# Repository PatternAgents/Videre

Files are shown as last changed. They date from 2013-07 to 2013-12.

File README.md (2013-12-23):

Videre
=============

PatternAgents Videre - LCD Shield with Cortex-M0

[PatternAgents Videre  
*PatternAgents Videre*](http://www.patternagents.com/projects/Videre.html)

The PatternAgents Videre uses an ARM Cortex-M0 based Programmable System-on-Chip (PSoC4) 
to control a 16x2 Character LCD with color backlighting. The PSoC4  can read read inputs from sensors, 
switches, potentiometers, or other analog inputs and display those sensors directly on the LCD in
standalone mode. Or you can use it as an Arduino Shield, with either I2C,, UART, or SPI interface.

Features:

        16 Character x 2 Line Display

        Color LED Backlighting
	
        Selectable 3.3Volt or 5.0Volt Operation
	
        UART, I2C, SPI Interface Selectable
	
        Use as Arduino Shield or as a Standalone Display
	
        CapSense Slider Bar (optional)      

	Arduino Uno/Leonardo/Mega/Due Compatible Shield

You can read more about the PSoC4 Integrated Circuit used here : http://www.cypress.com/?mpn=CY8C4245AXI-483

[  
*Licensing CC BY-NC-SA 4.0*](http://creativecommons.org/licenses/by-nc-sa/4.0/)

PatternAgents uses the increasingly popular business model called "Dual Licensing" 
in which both the open source software distribution mechanism and traditional commercial software distribution models are combined.

Open Source Projects:        

If you are developing and distributing open source applications under the Creative Commons CC BY-NC-SA 4.0, 
as published by the Creative Commons Foundation, then you are free to use the PatternAgents hardware/software under the CC BY-NC-SA 4.0 license. 
Please note that CC BY-NC-SA 4.0 requires that all modifications to the original code as well as all Derivative Works 
must also be released under the terms of the CC BY-NC-SA 4.0 license.

Closed Source Projects:

If you are developing and distributing traditional closed source or commercial applications, 
you must purchase a PatternAgents commercial use license, 
which is specifically designed for users interested in retaining the proprietary status of their designs and code. 
All PatternAgents commercial licenses expressly supersede the CC BY-NC-SA 4.0 license. 
This means that when you license the PatternAgents software under a commercial license, 
you specifically do not use the software under the CC BY-NC-SA 4.0 license and therefore you are not subject to any of its terms.
        
If you would like to use our designs for your own personal or educational use, have at it! 

Our public design repository is available at <a href="https://github.com/patternagents">Github</a>.

If you would like to produce our designs for commercial use, or as products for sale, 
please contact us to arrange for a Commercial Use license. We have many other designs, 
as well as options and extras that are not released publicly. 
We will also customize designs, firmware, and software for a reasonable fee, just contact us to discuss your requirements.

THIS SOFTWARE IS PROVIDED BY THE CONTRIBUTORS "AS IS" AND WITHOUT ANY EXPRESS OR IMPLIED WARRANTIES, 
INCLUDING, BUT NOT LIMITED TO, THE IMPLIED WARRANTIES OF MERCHANTABILITY AND FITNESS FOR A PARTICULAR PURPOSE ARE DISCLAIMED. 
IN NO EVENT SHALL THE COPYRIGHT OWNER OR CONTRIBUTORS BE LIABLE FOR ANY DIRECT, INDIRECT, INCIDENTAL, SPECIAL, EXEMPLARY, 
OR CONSEQUENTIAL DAMAGES (INCLUDING, BUT NOT LIMITED TO, PROCUREMENT OF SUBSTITUTE GOODS OR SERVICES; LOSS OF USE, DATA, 
OR PROFITS; OR BUSINESS INTERRUPTION) HOWEVER CAUSED AND ON ANY THEORY OF LIABILITY, WHETHER IN CONTRACT, 
STRICT LIABILITY, OR TORT (INCLUDING NEGLIGENCE OR OTHERWISE) ARISING IN ANY WAY OUT OF THE USE OF THIS SOFTWARE, 
EVEN IF ADVISED OF THE POSSIBILITY OF SUCH DAMAGE. 

-------------------------------------------------------------------------------------------

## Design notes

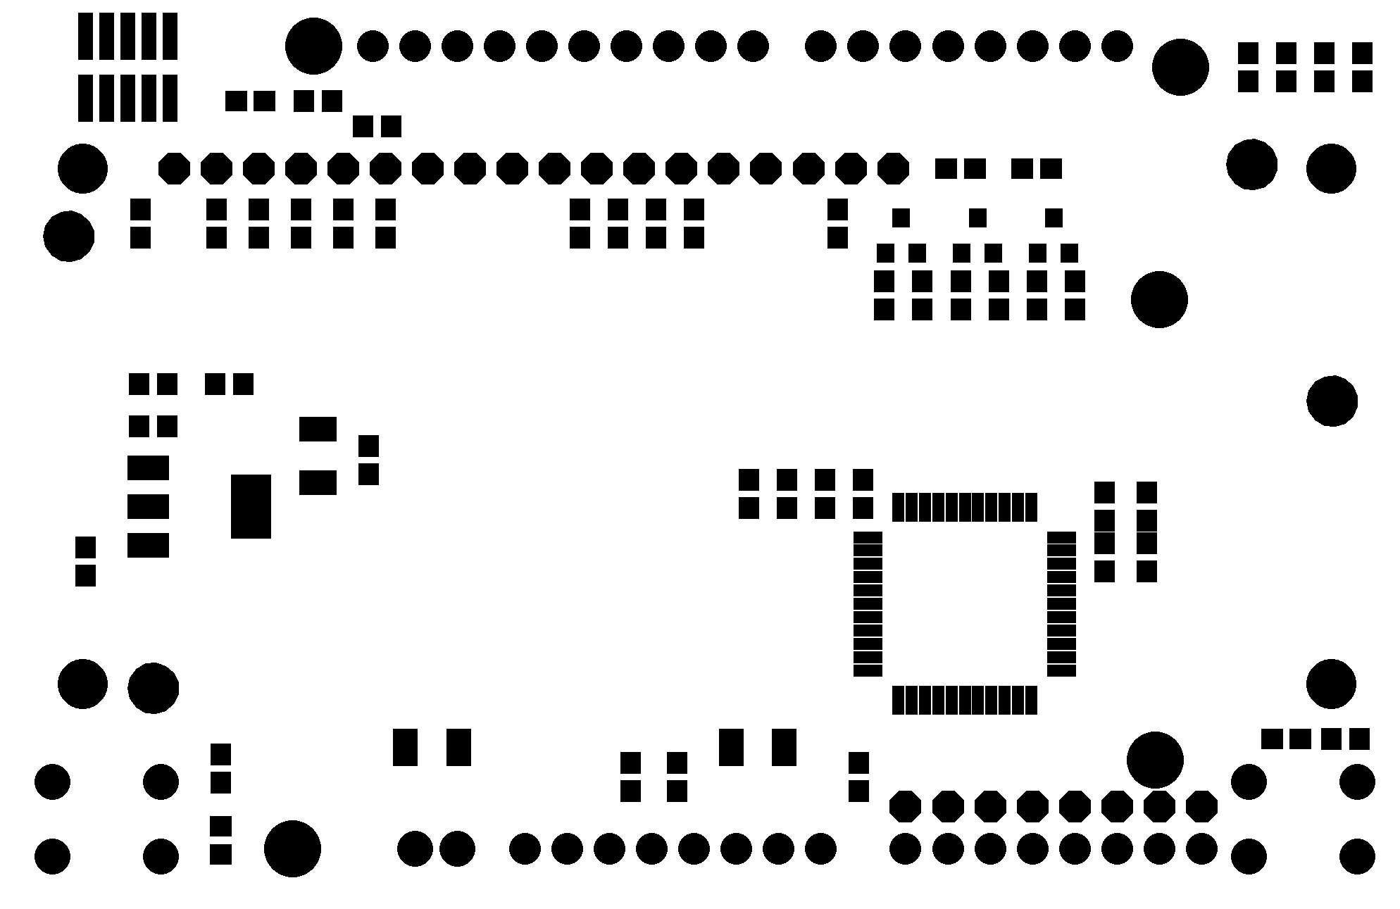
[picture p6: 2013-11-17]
Videre/eagleUp/eagleUp_Videre_top_mask.png

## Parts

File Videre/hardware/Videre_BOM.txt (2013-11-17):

Partlist  at 6/29/2013 11:25:48 AM eagle/PatternAgents/Arduino/Videre/Videre/Videre.sch

Part   Value                 Device                Package               Description                                                     
C1     0.1uF                 CAP0603-CAP           0603-CAP              Capacitor                                                       
C2     0.1uF                 CAP0603-CAP           0603-CAP              Capacitor                                                       
C3     1uF                   CAP0603-CAP           0603-CAP              Capacitor                                                       
C4     0.1uF                 CAP0603-CAP           0603-CAP              Capacitor                                                       
C5     1uF                   CAP0603-CAP           0603-CAP              Capacitor                                                       
C6     0.1uF                 CAP0603-CAP           0603-CAP              Capacitor                                                       
C7     1uF                   CAP0603-CAP           0603-CAP              Capacitor                                                       
C8     10uF                  CAP1210               1210                  Capacitor                                                       
C9     10uF                  CAP1210               1210                  Capacitor                                                       
C10    10uF                  CAP1210               1210                  Capacitor                                                       
C11    0.1uF                 CAP0603-CAP           0603-CAP              Capacitor                                                       
C12    10nF                  CAP0603-CAP           0603-CAP              Capacitor                                                       
C13    0.1uF                 CAP0603-CAP           0603-CAP              Capacitor                                                       
C14    2.2nF                 CAP0603-CAP           0603-CAP              Capacitor                                                       
J1                           M02PTH                1X02                  Header 2                                                        
JTAG1                        JTAG-CORTEXM3         2X05_1.27MM_SMT       JTAG Programming Connector                                      
Q1     MOSFET-PCHANNELSMD    MOSFET-PCHANNELSMD    SOT23-3               Generic PMOSFET                                                 
Q2     MOSFET-PCHANNELSMD    MOSFET-PCHANNELSMD    SOT23-3               Generic PMOSFET                                                 
Q3     MOSFET-PCHANNELSMD    MOSFET-PCHANNELSMD    SOT23-3               Generic PMOSFET                                                 
R1     100                   RESISTOR_SFE0603-RES  0603-RES              Resistor                                                        
R2     10K                   RESISTOR_SFE0603-RES  0603-RES              Resistor                                                        
R3     10K                   RESISTOR_SFE0603-RES  0603-RES              Resistor                                                        
R4     10K                   RESISTOR_SFE0603-RES  0603-RES              Resistor                                                        
R5     10K                   RESISTOR_SFE0603-RES  0603-RES              Resistor                                                        
R6     10K                   RESISTOR_SFE0603-RES  0603-RES              Resistor                                                        
R7     10K                   RESISTOR_SFE0603-RES  0603-RES              Resistor                                                        
R8     10K                   RESISTOR_SFE0603-RES  0603-RES              Resistor                                                        
R9     10K                   RESISTOR_SFE0603-RES  0603-RES              Resistor                                                        
R10    0                     RESISTOR_SFE0603-RES  0603-RES              Resistor                                                        
R11    10K                   RESISTOR_SFE0603-RES  0603-RES              Resistor                                                        
R12    0                     RESISTOR_SFE0603-RES  0603-RES              Resistor                                                        
R13    10K                   RESISTOR_SFE0603-RES  0603-RES              Resistor                                                        
R14    0                     RESISTOR_SFE0603-RES  0603-RES              Resistor                                                        
R15    10K                   RESISTOR_SFE0603-RES  0603-RES              Resistor                                                        
R16    4.7K                  RESISTORR0603         R0603                 RESISTOR, American symbol                                       
R17    4.7K                  RESISTORR0603         R0603                 RESISTOR, American symbol                                       
R20    4.7K                  RESISTOR_SFE0603-RES  0603-RES              Resistor                                                        
R21    10K                   RESISTOR_SFE0603-RES  0603-RES              Resistor                                                        
R22    10K                   RESISTOR_SFE0603-RES  0603-RES              Resistor                                                        
R23    0                     RESISTOR_SFE0603-RES  0603-RES              Resistor                                                        
R24    0                     RESISTOR_SFE0603-RES  0603-RES              Resistor                                                        
R25    0                     RESISTOR_SFE0603-RES  0603-RES              Resistor                                                        
R26    0                     RESISTOR_SFE0603-RES  0603-RES              Resistor                                                        
R27    0                     RESISTOR_SFE0603-RES  0603-RES              Resistor                                                        
R28    0                     RESISTOR_SFE0603-RES  0603-RES              Resistor                                                        
R29    240                   RESISTORR0603         R0603                 RESISTOR, American symbol                                       
R30    390                   RESISTORR0603         R0603                 RESISTOR, American symbol                                       
R31    330                   RESISTORR0603         R0603                 RESISTOR, American symbol                                       
R32    0                     RESISTOR_SFE0603-RES  0603-RES              Resistor                                                        
R33    330                   RESISTORR0603         R0603                 RESISTOR, American symbol                                       
R34    330                   RESISTORR0603         R0603                 RESISTOR, American symbol                                       
R35    180                   RESISTOR_SFE0603-RES  0603-RES              Resistor                                                        
R36    120                   RESISTOR_SFE0603-RES  0603-RES              Resistor                                                        
R37    120                   RESISTOR_SFE0603-RES  0603-RES              Resistor                                                        
S1     SWITCH-MOMENTARY-2PTH SWITCH-MOMENTARY-2PTH TACTILE-PTH           Various NO switches- pushbuttons, reed, etc                     
S2     SWITCH-MOMENTARY-2PTH SWITCH-MOMENTARY-2PTH TACTILE-PTH           Various NO switches- pushbuttons, reed, etc                     
SLIDER                       M081X08               1X08                  Header 8                                                        
LCD    LCD-16X2RGB           LCD-16X2RGB           LCD-16X2RGB                                                                           
U1     CY8C42XX-44PIN        CY8C42XX-44PIN        TQFP-10X10-44         Cypress PSoC® 4 - Programmable System on Chip,  Cortex-M0 Based 
U3     V_REG_317SMD          V_REG_317SMD          SOT223                Voltage Regulator

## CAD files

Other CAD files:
Videre/eagleUp/videre.skp

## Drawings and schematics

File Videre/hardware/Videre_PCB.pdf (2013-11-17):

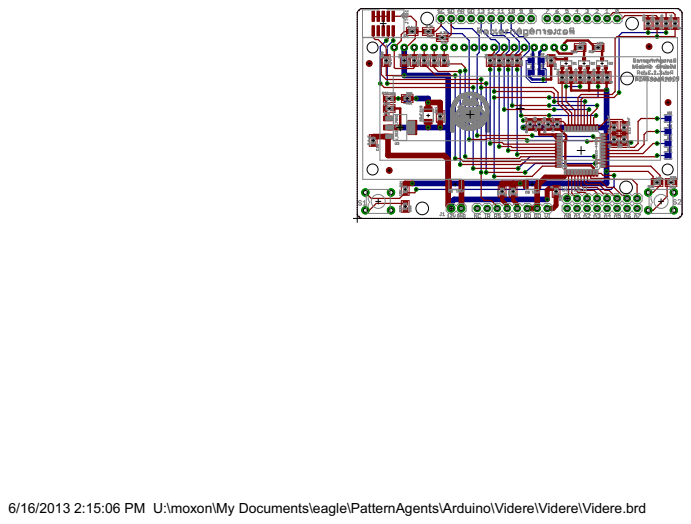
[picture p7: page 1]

6/16/2013 2:15:06 PM U:\moxon\My Documents\eagle\PatternAgents\Arduino\Videre\Videre\Videre.brd

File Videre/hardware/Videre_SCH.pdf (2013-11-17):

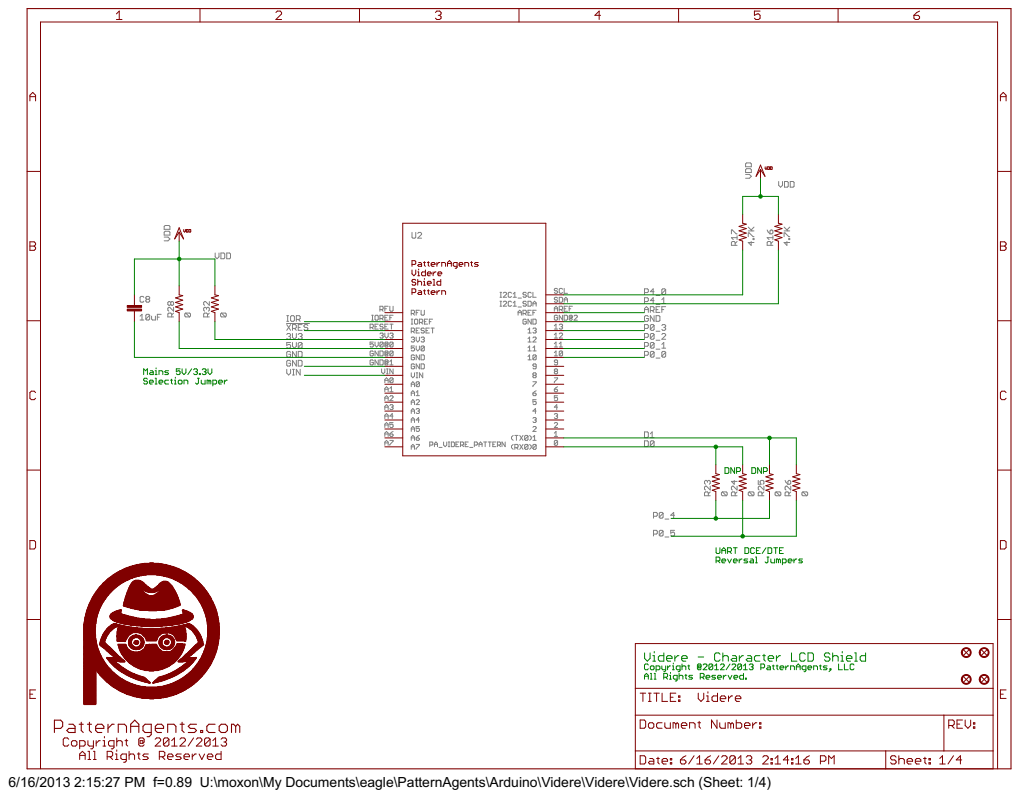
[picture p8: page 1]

6/16/2013 2:15:27 PM f=0.89 U:\moxon\My Documents\eagle\PatternAgents\Arduino\Videre\Videre\Videre.sch (Sheet: 1/4)

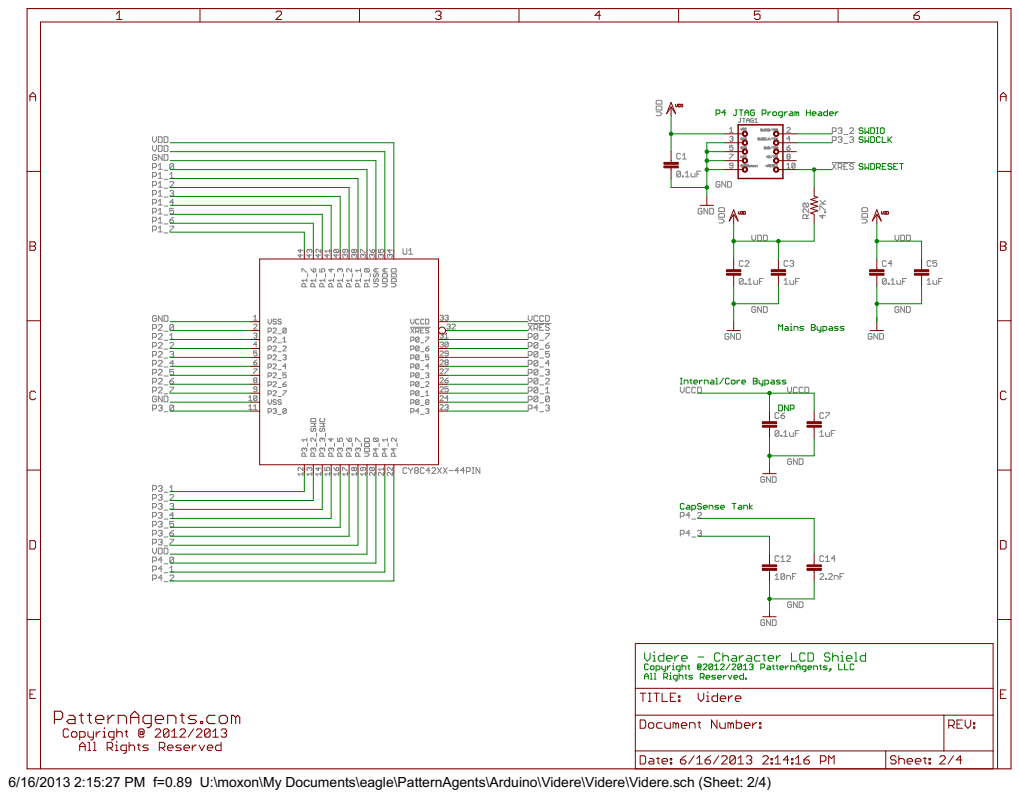
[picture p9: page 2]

6/16/2013 2:15:27 PM f=0.89 U:\moxon\My Documents\eagle\PatternAgents\Arduino\Videre\Videre\Videre.sch (Sheet: 2/4)

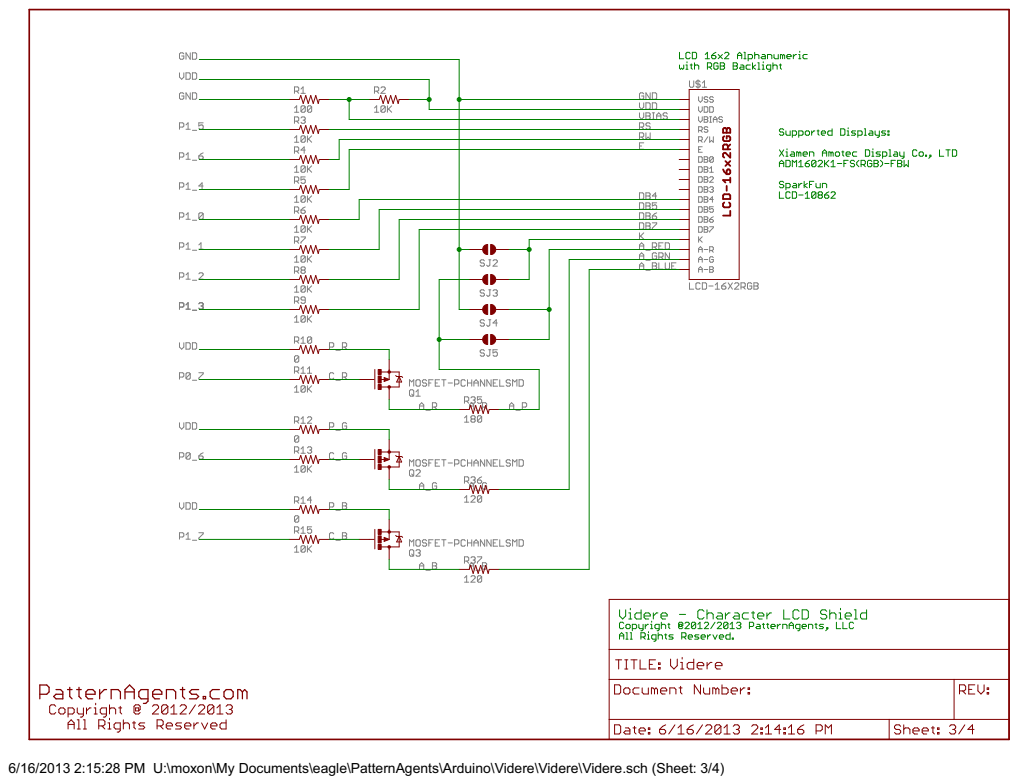
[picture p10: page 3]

6/16/2013 2:15:28 PM U:\moxon\My Documents\eagle\PatternAgents\Arduino\Videre\Videre\Videre.sch (Sheet: 3/4)

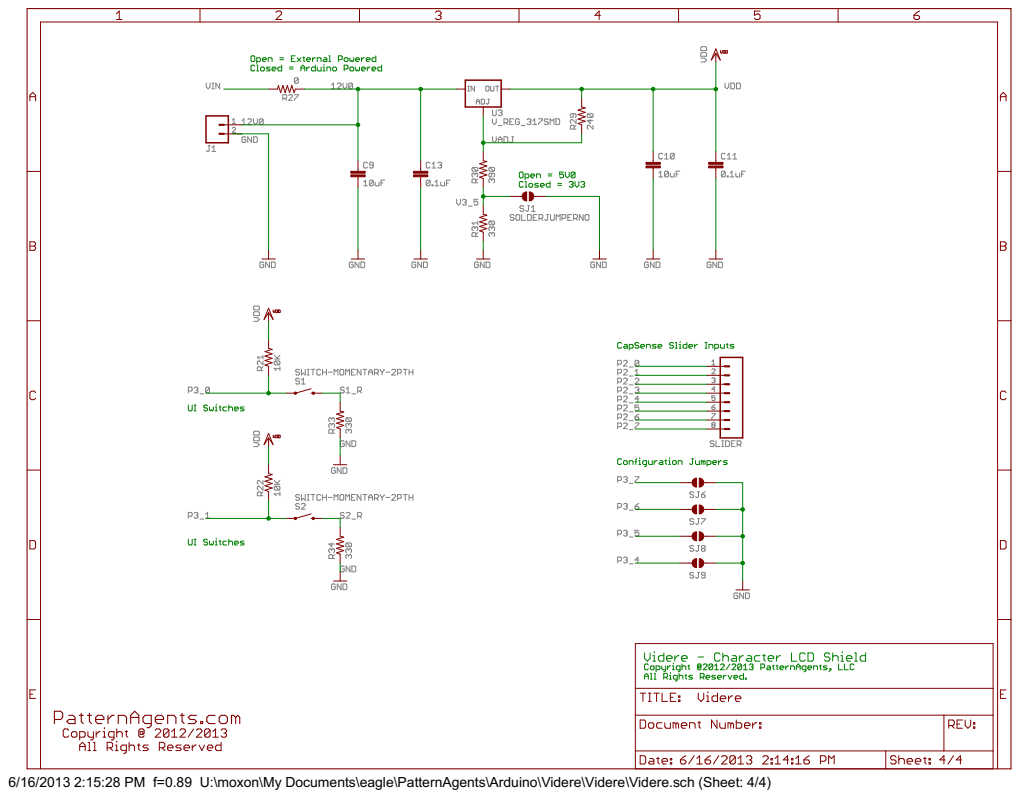
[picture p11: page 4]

6/16/2013 2:15:28 PM f=0.89 U:\moxon\My Documents\eagle\PatternAgents\Arduino\Videre\Videre\Videre.sch (Sheet: 4/4)

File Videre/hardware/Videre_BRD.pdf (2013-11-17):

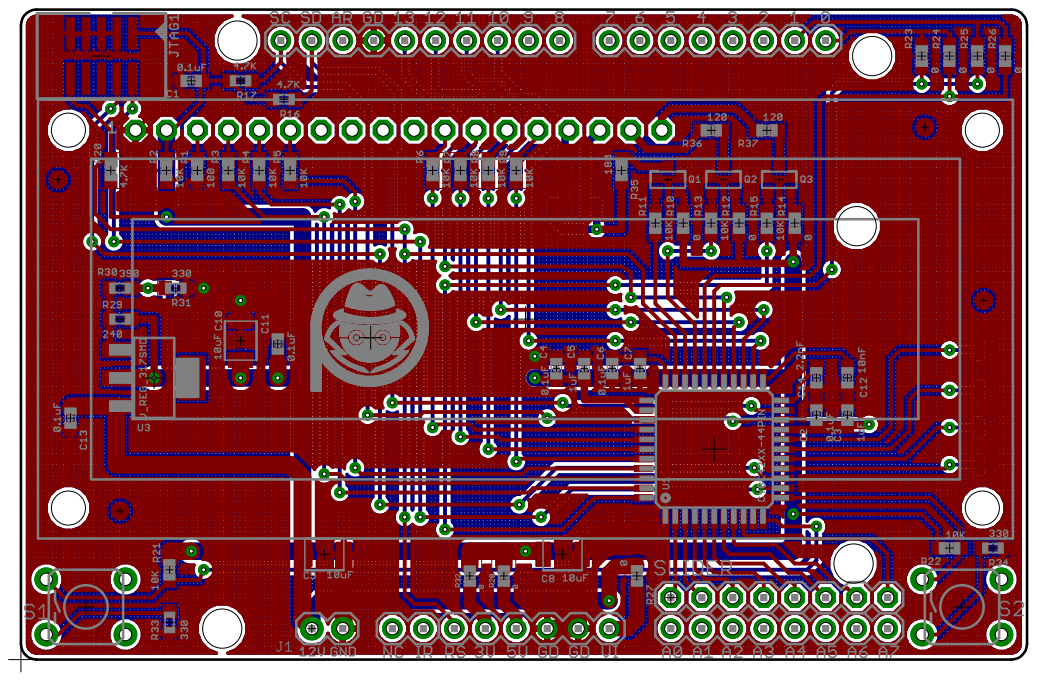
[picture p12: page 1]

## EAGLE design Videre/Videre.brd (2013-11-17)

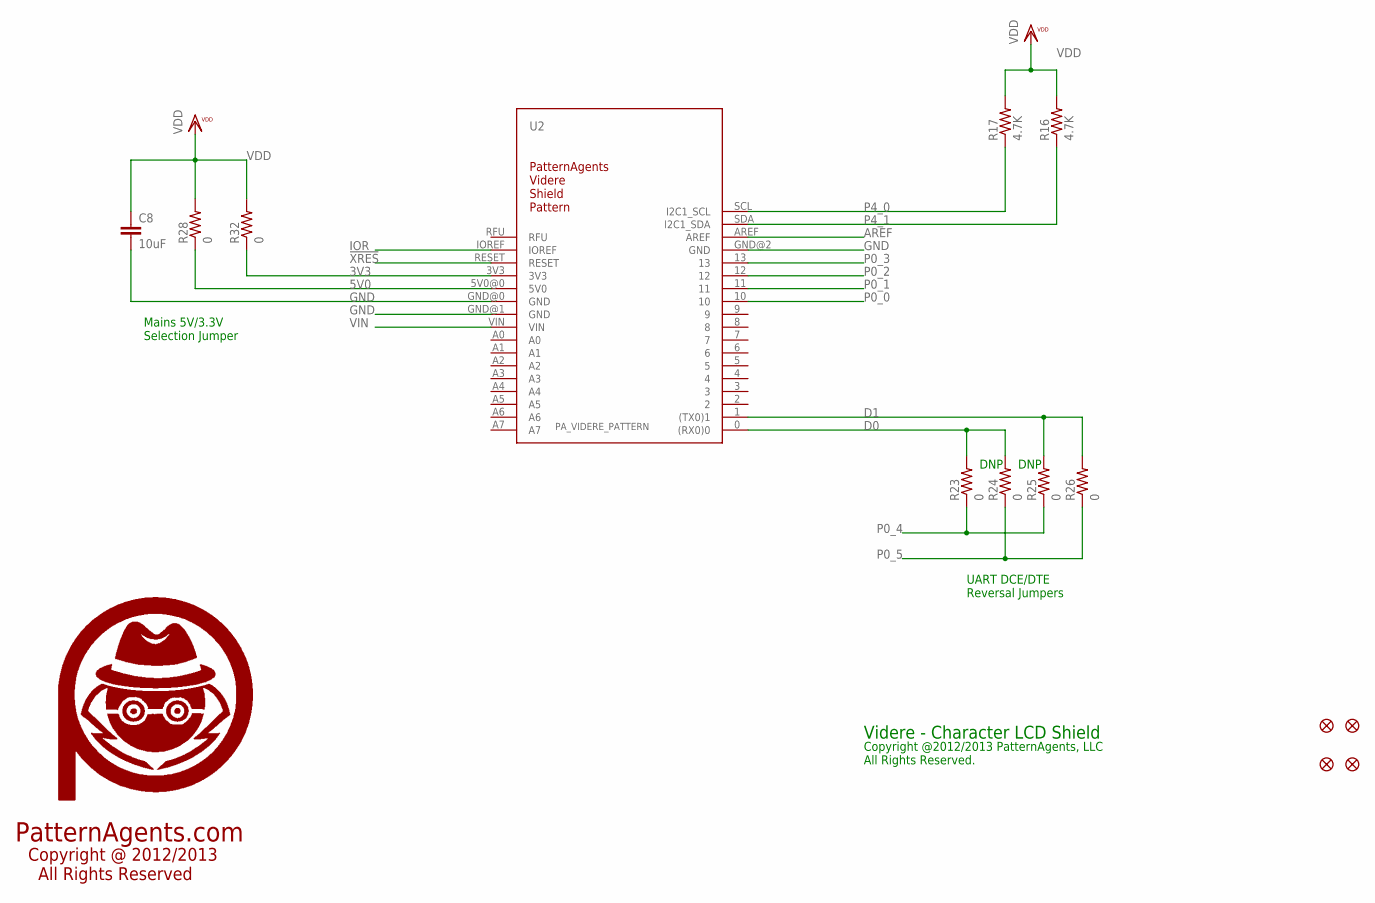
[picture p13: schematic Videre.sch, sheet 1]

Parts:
C8: 10uF; 1210
FID1, FID2, FID3, FID4: FIDUCIAL1.5X3; FIDUCIAL-1.5X3
R16, R17: 4.7K; R0603
R23, R24, R25, R26: 0; 0603-RES
R28, R32: 0; 0603-RES@1
U2: PA_VIDERE_PATTERN
U$3: PA_LOGO_SYMLARGE; PA_LOGO_AGENT_LRG_SYM

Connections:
3V3: R32.1, U2.3V3
5V0: R28.1, U2.5V0@0 (5V0)
!XRES: U2.RESET; also elsewhere on the board
AREF: U2.AREF
D0: R23.2, R24.2, U2.0 ((RX0)0)
D1: R25.2, R26.2, U2.1 ((TX0)1)
GND: C8.2, U2.GND@0 (GND), U2.GND@1 (GND), U2.GND@2 (GND); also elsewhere on the board
IOR: U2.IOREF
P0_0: U2.10; also elsewhere on the board
P0_1: U2.11; also elsewhere on the board
P0_2: U2.12; also elsewhere on the board
P0_3: U2.13; also elsewhere on the board
P0_4: R23.1, R25.1; also elsewhere on the board
P0_5: R24.1, R26.1; also elsewhere on the board
P4_0: R17.1, U2.SCL (I2C1_SCL); also elsewhere on the board
P4_1: R16.1, U2.SDA (I2C1_SDA); also elsewhere on the board
RFU: U2.RFU
VDD: C8.1, R16.2, R17.2, R28.2, R32.2; also elsewhere on the board
VIN: U2.VIN; also elsewhere on the board

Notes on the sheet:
DNP
UART DCE/DTE Reversal Jumpers
Mains 5V/3.3V Selection Jumper
PatternAgents.com
Copyright @ 2012/2013 All Rights Reserved
Videre - Character LCD Shield
Copyright @2012/2013 PatternAgents, LLC All Rights Reserved.

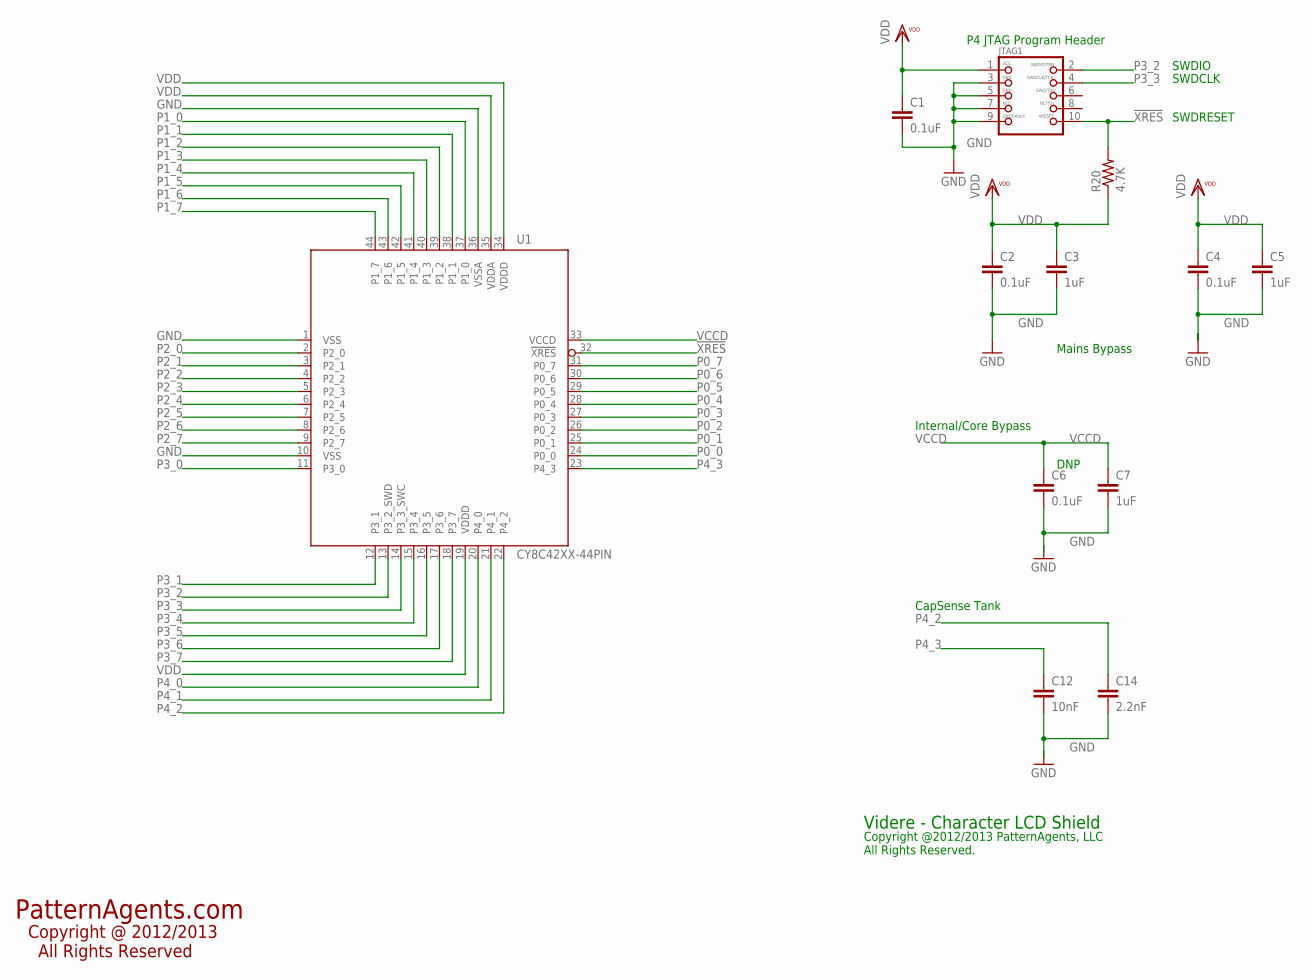
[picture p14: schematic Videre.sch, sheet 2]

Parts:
C1, C2, C4, C6: 0.1uF; 0603-CAP
C3, C5, C7: 1uF; 0603-CAP
C12: 10nF; 0603-CAP
C14: 2.2nF; 0603-CAP
JTAG1: JTAG-CORTEXM3; 2X05_1.27MM_SMT
R20: 4.7K; 0603-RES
U1: CY8C42XX-44PIN; TQFP-10X10-44

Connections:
!XRES: JTAG1.10, R20.2, U1.32 (!XRES); also elsewhere on the board
GND: C1.2, C2.2, C3.2, C4.2, C5.2, C6.2, C7.2, C12.2, C14.2, JTAG1.3, JTAG1.5, JTAG1.7, JTAG1.9, U1.1 (VSS), U1.10 (VSS), U1.36 (VSSA); also elsewhere on the board
P0_0: U1.24 (P0_0); also elsewhere on the board
P0_1: U1.25 (P0_1); also elsewhere on the board
P0_2: U1.26 (P0_2); also elsewhere on the board
P0_3: U1.27 (P0_3); also elsewhere on the board
P0_4: U1.28 (P0_4); also elsewhere on the board
P0_5: U1.29 (P0_5); also elsewhere on the board
P0_6: U1.30 (P0_6); also elsewhere on the board
P0_7: U1.31 (P0_7); also elsewhere on the board
P1_0: U1.37 (P1_0); also elsewhere on the board
P1_1: U1.38 (P1_1); also elsewhere on the board
P1_2: U1.39 (P1_2); also elsewhere on the board
P1_3: U1.40 (P1_3); also elsewhere on the board
P1_4: U1.41 (P1_4); also elsewhere on the board
P1_5: U1.42 (P1_5); also elsewhere on the board
P1_6: U1.43 (P1_6); also elsewhere on the board
P1_7: U1.44 (P1_7); also elsewhere on the board
P2_0: U1.2 (P2_0); also elsewhere on the board
P2_1: U1.3 (P2_1); also elsewhere on the board
P2_2: U1.4 (P2_2); also elsewhere on the board
P2_3: U1.5 (P2_3); also elsewhere on the board
P2_4: U1.6 (P2_4); also elsewhere on the board
P2_5: U1.7 (P2_5); also elsewhere on the board
P2_6: U1.8 (P2_6); also elsewhere on the board
P2_7: U1.9 (P2_7); also elsewhere on the board
P3_0: U1.11 (P3_0); also elsewhere on the board
P3_1: U1.12 (P3_1); also elsewhere on the board
P3_2: JTAG1.2, U1.13 (P3_2_SWD)
P3_3: JTAG1.4, U1.14 (P3_3_SWC)
P3_4: U1.15 (P3_4); also elsewhere on the board
P3_5: U1.16 (P3_5); also elsewhere on the board
P3_6: U1.17 (P3_6); also elsewhere on the board
P3_7: U1.18 (P3_7); also elsewhere on the board
P4_0: U1.20 (P4_0); also elsewhere on the board
P4_1: U1.21 (P4_1); also elsewhere on the board
P4_2: C14.1, U1.22 (P4_2)
P4_3: C12.1, U1.23 (P4_3)
VCCD: C6.1, C7.1, U1.33 (VCCD)
VDD: C1.1, C2.1, C3.1, C4.1, C5.1, JTAG1.1, R20.1, U1.19 (VDDD), U1.34 (VDDD), U1.35 (VDDA); also elsewhere on the board

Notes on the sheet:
SWDIO
SWDCLK
SWDRESET
P4 JTAG Program Header
DNP
CapSense Tank
Internal/Core Bypass
Mains Bypass
Videre - Character LCD Shield
Copyright @2012/2013 PatternAgents, LLC All Rights Reserved.
PatternAgents.com
Copyright @ 2012/2013 All Rights Reserved

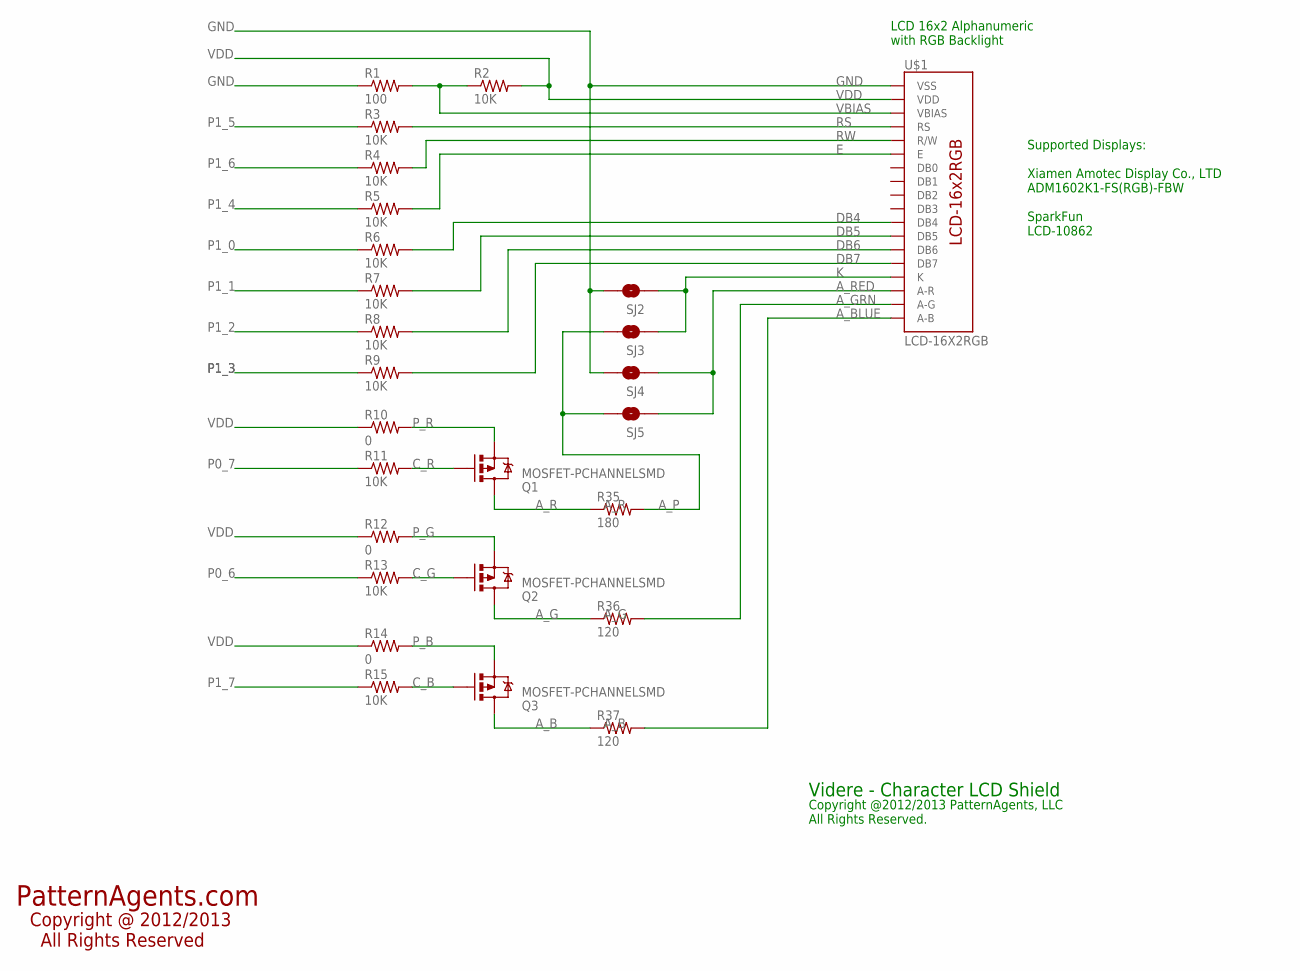
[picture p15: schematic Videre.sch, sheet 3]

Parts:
Q1, Q2, Q3: MOSFET-PCHANNELSMD; SOT23-3
R1: 100; 0603-RES
R2, R3, R4, R5, R6, R7, R8, R9, R11, R13, R15: 10K; 0603-RES
R10, R12, R14: 0; 0603-RES
R35: 180; 0603-RES
R36, R37: 120; 0603-RES
SJ2, SJ3, SJ4, SJ5: SOLDERJUMPERNO; SJ_2S-NO
U$1: LCD-16X2RGB

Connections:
A_B: Q3.3 (D), R37.1
A_BLUE: R37.2, U$1.18 (A-B)
A_G: Q2.3 (D), R36.1
A_GRN: R36.2, U$1.17 (A-G)
A_P: R35.2, SJ3.2, SJ5.2
A_R: Q1.3 (D), R35.1
A_RED: SJ4.1, SJ5.1, U$1.16 (A-R)
C_B: Q3.1 (G), R15.2
C_G: Q2.1 (G), R13.2
C_R: Q1.1 (G), R11.2
DB4: R6.2, U$1.11 (DB4)
DB5: R7.2, U$1.12 (DB5)
DB6: R8.2, U$1.13 (DB6)
DB7: R9.2, U$1.14 (DB7)
E: R5.2, U$1.6 (E)
GND: R1.1, SJ2.2, SJ4.2, U$1.1 (VSS); also elsewhere on the board
K: SJ2.1, SJ3.1, U$1.15 (K)
P0_6: R13.1; also elsewhere on the board
P0_7: R11.1; also elsewhere on the board
P1_0: R6.1; also elsewhere on the board
P1_1: R7.1; also elsewhere on the board
P1_2: R8.1; also elsewhere on the board
P1_3: R9.1; also elsewhere on the board
P1_4: R5.1; also elsewhere on the board
P1_5: R3.1; also elsewhere on the board
P1_6: R4.1; also elsewhere on the board
P1_7: R15.1; also elsewhere on the board
P_B: Q3.2 (S), R14.2
P_G: Q2.2 (S), R12.2
P_R: Q1.2 (S), R10.2
RS: R3.2, U$1.4 (RS)
RW: R4.2, U$1.5 (R/W)
VBIAS: R1.2, R2.1, U$1.3 (VBIAS)
VDD: R2.2, R10.1, R12.1, R14.1, U$1.2 (VDD); also elsewhere on the board

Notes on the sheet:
LCD 16x2 Alphanumeric with RGB Backlight
Supported Displays: Xiamen Amotec Display Co., LTD ADM1602K1-FS(RGB)-FBW SparkFun LCD-10862
Videre - Character LCD Shield
Copyright @2012/2013 PatternAgents, LLC All Rights Reserved.
PatternAgents.com
Copyright @ 2012/2013 All Rights Reserved

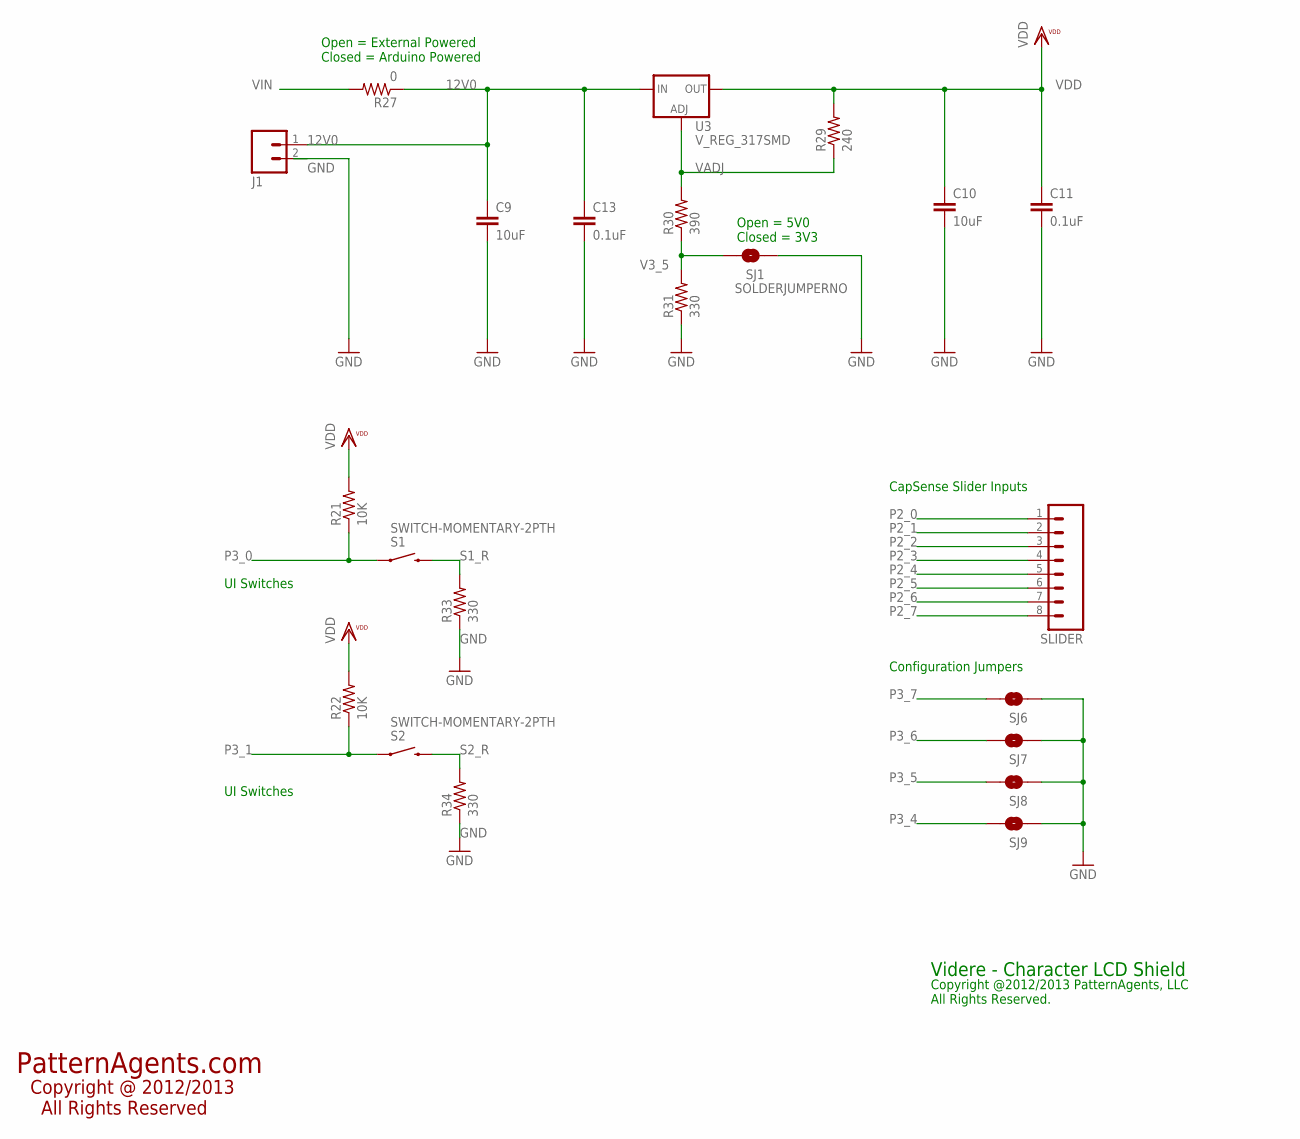
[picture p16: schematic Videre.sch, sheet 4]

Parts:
C9, C10: 10uF; 1210
C11, C13: 0.1uF; 0603-CAP
J1: M02PTH; 1X02
R21, R22: 10K; 0603-RES
R27: 0; 0603-RES
R29: 240; R0603
R30: 390; R0603
R31, R33, R34: 330; R0603
S1, S2: SWITCH-MOMENTARY-2PTH; TACTILE-PTH
SJ1, SJ6, SJ7, SJ8, SJ9: SOLDERJUMPERNO; SJ_2S-NO
SLIDER: M081X08; 1X08
U3: V_REG_317SMD; SOT223

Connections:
12V0: C9.1, C13.1, J1.1, R27.1, U3.3 (IN)
GND: C9.2, C10.2, C11.2, C13.2, J1.2, R31.1, R33.1, R34.1, SJ1.1, SJ6.1, SJ7.1, SJ8.1, SJ9.1; also elsewhere on the board
P2_0: SLIDER.1; also elsewhere on the board
P2_1: SLIDER.2; also elsewhere on the board
P2_2: SLIDER.3; also elsewhere on the board
P2_3: SLIDER.4; also elsewhere on the board
P2_4: SLIDER.5; also elsewhere on the board
P2_5: SLIDER.6; also elsewhere on the board
P2_6: SLIDER.7; also elsewhere on the board
P2_7: SLIDER.8; also elsewhere on the board
P3_0: R21.1, S1.1; also elsewhere on the board
P3_1: R22.1, S2.1; also elsewhere on the board
P3_4: SJ9.2; also elsewhere on the board
P3_5: SJ8.2; also elsewhere on the board
P3_6: SJ7.2; also elsewhere on the board
P3_7: SJ6.2; also elsewhere on the board
S1_R: R33.2, S1.3 (2)
S2_R: R34.2, S2.3 (2)
V3_5: R30.1, R31.2, SJ1.2
VADJ: R29.1, R30.2, U3.1 (ADJ)
VDD: C10.1, C11.1, R21.2, R22.2, R29.2, U3.2 (OUT); also elsewhere on the board
VIN: R27.2; also elsewhere on the board

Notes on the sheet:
Open = 5V0 Closed = 3V3
Open = External Powered Closed = Arduino Powered
CapSense Slider Inputs
Configuration Jumpers
UI Switches
Videre - Character LCD Shield
Copyright @2012/2013 PatternAgents, LLC All Rights Reserved.
PatternAgents.com
Copyright @ 2012/2013 All Rights Reserved

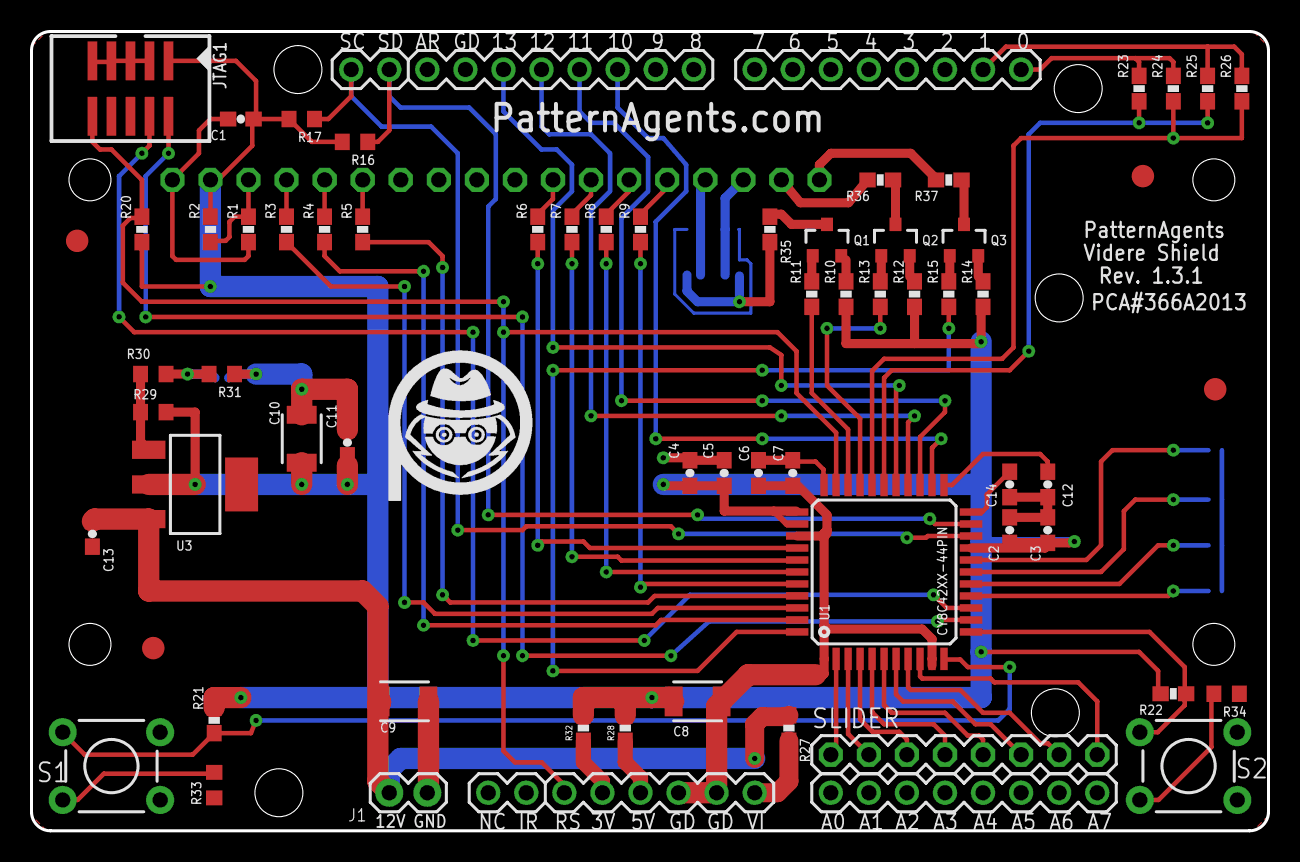
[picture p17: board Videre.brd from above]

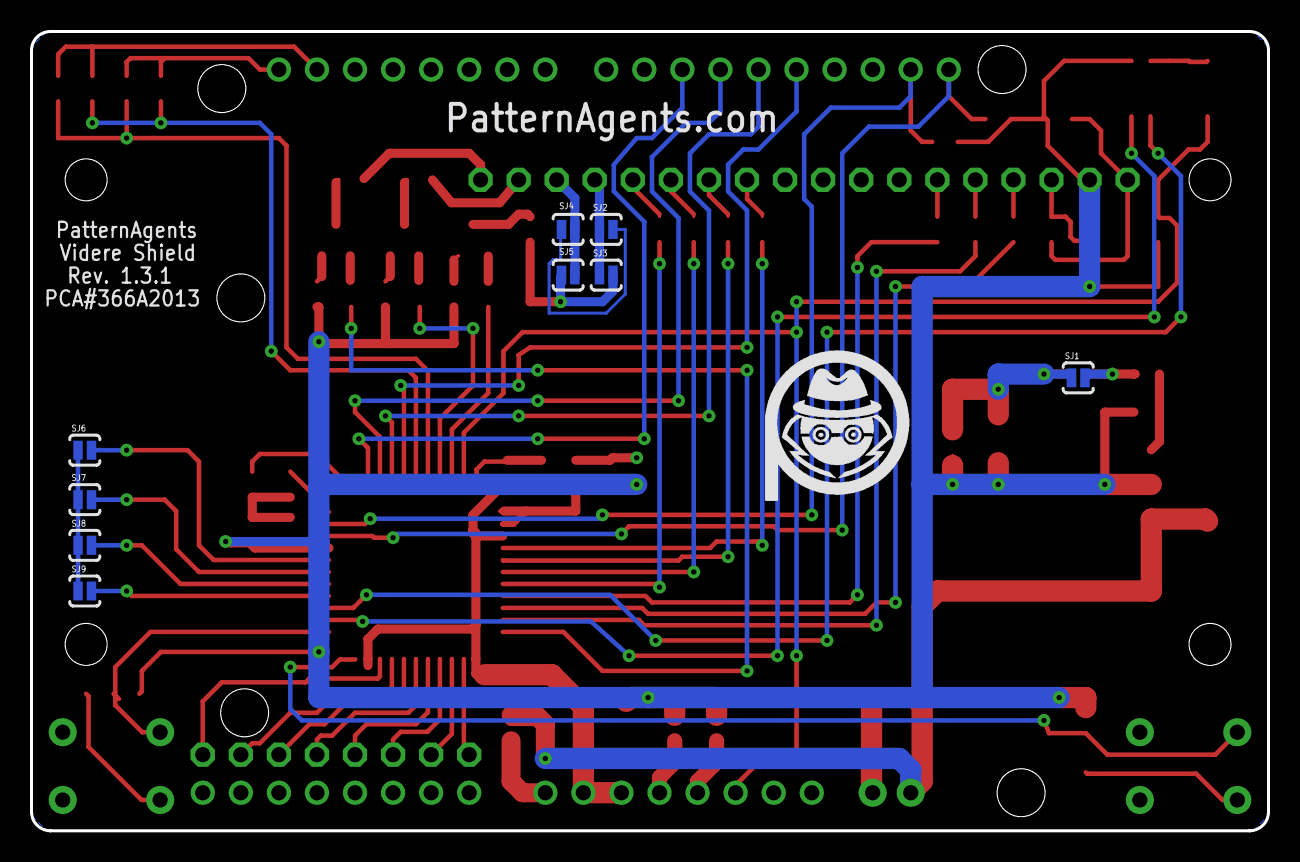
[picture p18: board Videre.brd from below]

Board: 2 copper layers, 82.5 x 53.3 mm, 76 parts (10 on the bottom side), 72 nets.

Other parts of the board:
U$2: PA_LOGO_SYMLARGE; PA_LOGO_AGENT_LRG_SYM

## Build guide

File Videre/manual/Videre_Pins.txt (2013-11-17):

Arduino :
SCL	P4_0
SDA	P4_1
AREF	NC
D13	P0_3	SCK
D12	P0_2	MISO
D11	P0_1	MOSI
D10	P0_0	SS
D9	NC
D8	NC
D7	NC
D6	NC
D5	NC
D4	NC
D3	NC
D2	NC
D1	P0_4
D0	P0_5
A7-A0	NC

LCD:
RS	P1_5
RW	P1_6
E	P1_4
DB4	P1_0
DB5	P1_1
DB6	P1_2
DB7	P1_3
RED	P0_7
GREEN	P0_6
BLUE	P1_7

Configuration Jumpers
SJ6	P3_7
SJ7	P3_6
SJ8	P3_5
SJ9	P3_4

Pushbuttons:
S1	P3_0
S1	P3_1

JTAG:
SWDIO	P3_2
SWDCLK	P3_3
XRES	XRES

CapSense (Slider) :
Tank	P4_2
Tank	P4_3
S1	P2_0
S2	P2_1
S3	P2_2
S4	P2_3
S5	P2_4
S6	P2_5
S7	P2_6
S8	P2_7

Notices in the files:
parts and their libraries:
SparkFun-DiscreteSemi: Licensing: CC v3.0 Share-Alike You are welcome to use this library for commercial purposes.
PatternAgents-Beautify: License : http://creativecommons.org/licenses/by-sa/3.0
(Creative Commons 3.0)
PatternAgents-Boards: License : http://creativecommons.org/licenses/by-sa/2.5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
